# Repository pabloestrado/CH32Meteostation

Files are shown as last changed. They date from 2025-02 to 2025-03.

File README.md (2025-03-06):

# CH32 Meteostation

This project is a meteostation using the CH32V003A4M6 microcontroller. It includes functionalities for measuring temperature, humidity, and pressure, and displays the data on an SSD1306 OLED screen. The project also supports Bluetooth communication for remote data access.

## Features

- Temperature and humidity measurement using AHT20 sensor
- Pressure measurement using BMP280 sensor
- Display data on SSD1306 OLED screen
- Bluetooth communication using JDY-23 module
- Battery voltage monitoring
- Deep sleep mode for power saving

## Hardware Requirements

- CH32 microcontroller
- AHT20 temperature and humidity sensor
- BMP280 pressure sensor
- SSD1306 OLED display
- JDY-23 Bluetooth module
- Battery and power management components

## Software Requirements

- PlatformIO
- CH32V003 SDK
- I2C, UART, and GPIO libraries

## Setup

1. Clone the repository:
    ```sh
    git clone https://github.com/yourusername/CH32Meteostation.git
    cd CH32Meteostation
    ```

2. Open the project in PlatformIO:
    ```sh
    platformio init --board ch32v003
    ```

3. Build and upload the firmware:
    ```sh
    platformio run --target upload
    ```

## Usage

1. Power on the device.
2. The device will initialize and start measuring the environmental data.
3. The data will be displayed on the OLED screen.
4. Use a Bluetooth-enabled device to connect and retrieve data remotely.

## Code Overview

- `main.c`: The main application code, including initialization, measurement, display, and communication functions.
- `i2c.c` and `i2c.h`: I2C communication functions.
- `uart.c` and `uart.h`: UART communication functions.
- `ssd1306.c` and `ssd1306.h`: SSD1306 OLED display functions.
- `bmp280.c` and `bmp280.h`: BMP280 sensor functions.
- `aht20.c` and `aht20.h`: AHT20 sensor functions.

## License

This project is licensed under the MIT License. See the [LICENSE](LICENSE) file for details.

## Acknowledgements

- [PlatformIO](https://platformio.org/)
- [ch32fun](https://github.com/cnlohr/ch32fun)

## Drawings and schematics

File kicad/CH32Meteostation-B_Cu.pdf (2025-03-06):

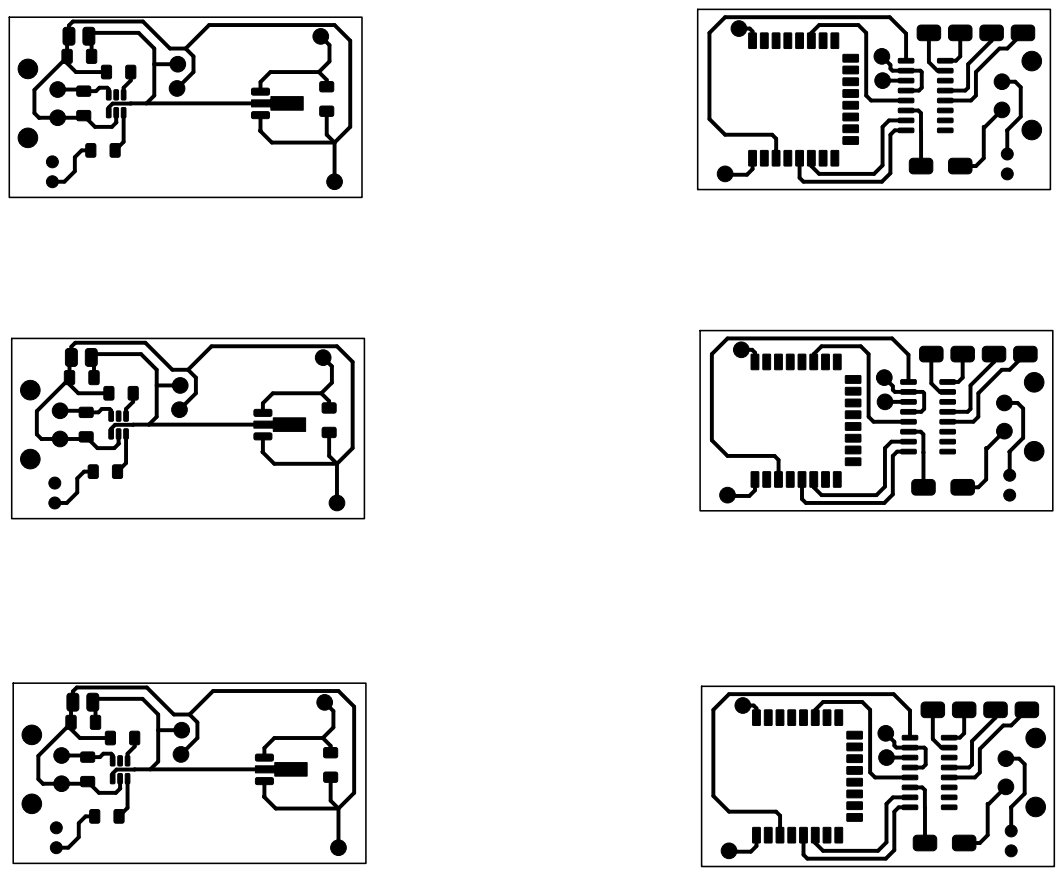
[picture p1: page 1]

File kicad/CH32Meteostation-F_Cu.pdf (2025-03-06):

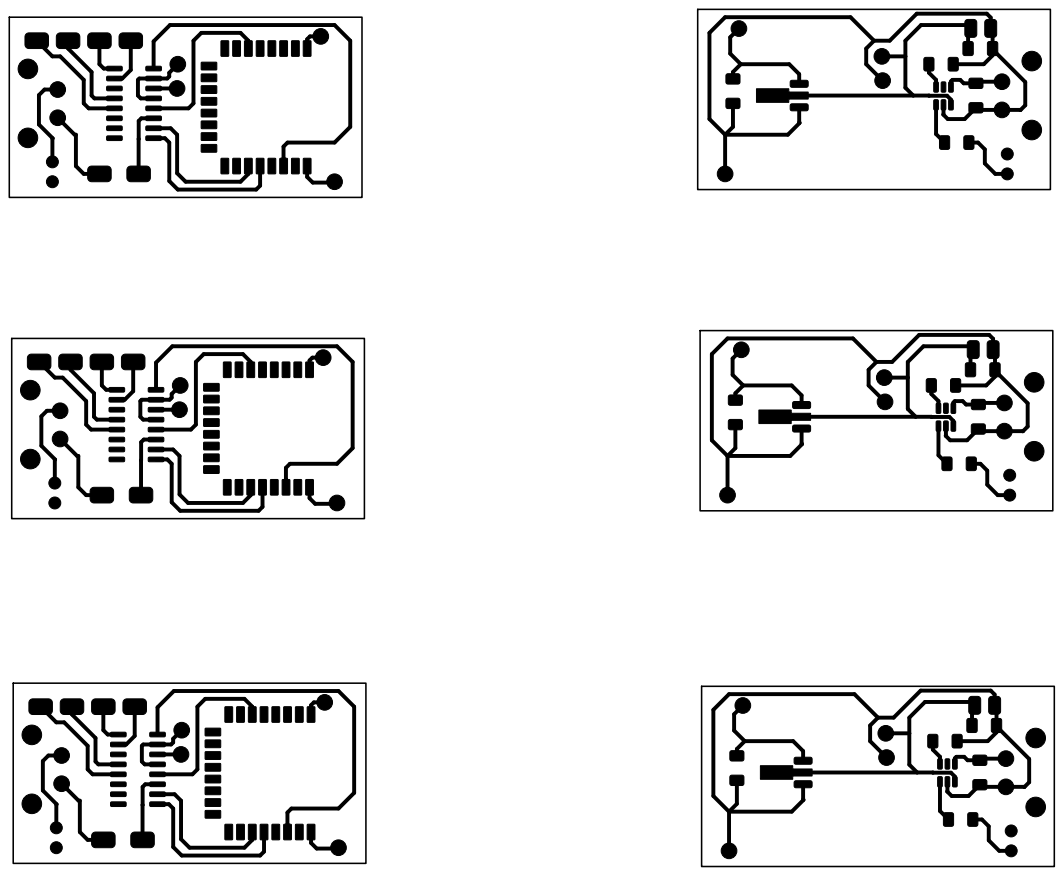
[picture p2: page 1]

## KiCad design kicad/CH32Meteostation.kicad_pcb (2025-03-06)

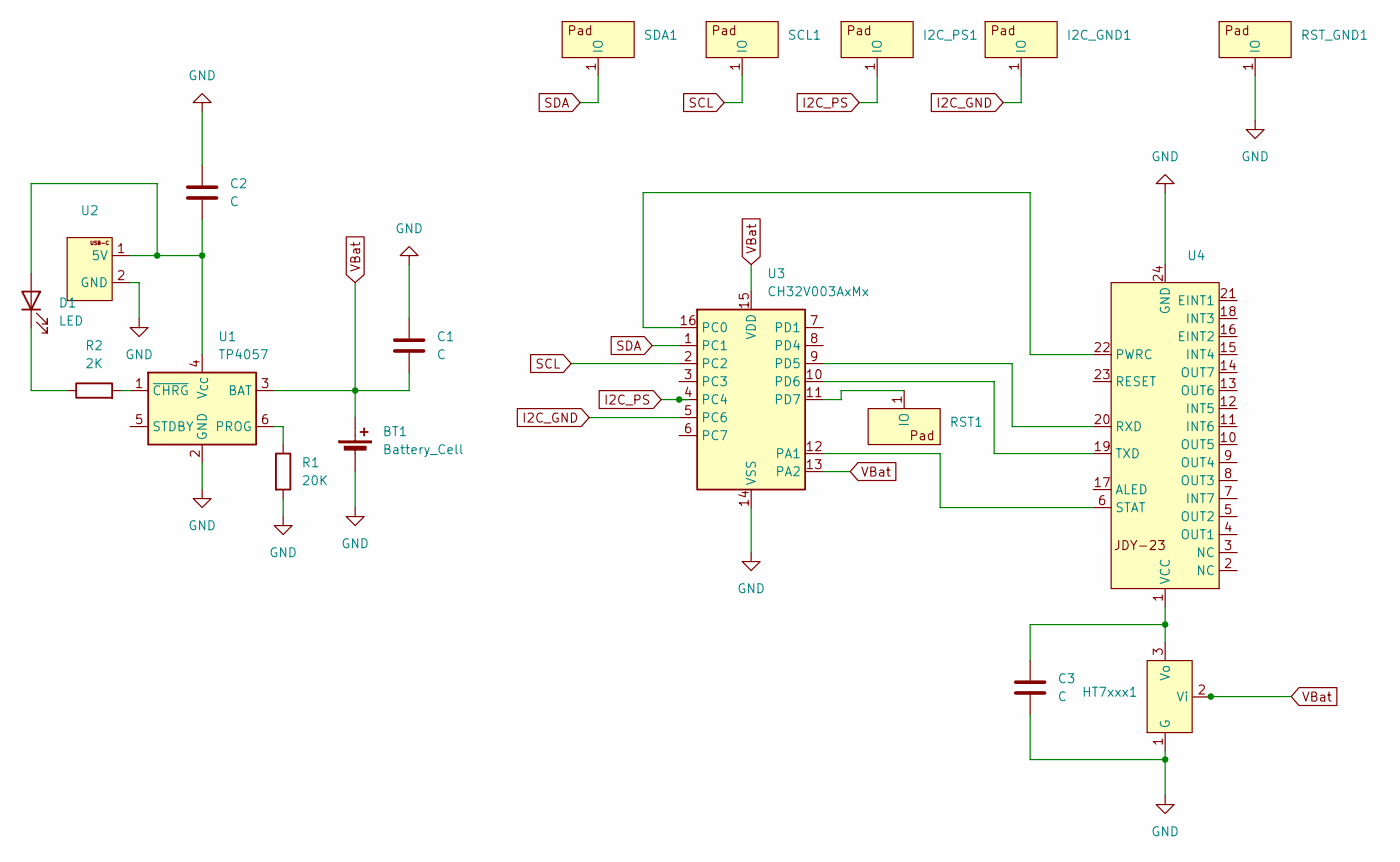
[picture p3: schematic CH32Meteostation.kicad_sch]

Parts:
BT1: Battery_Cell; 2-pin soldering pad
C1, C2, C3: C; C_1206_3216Metric_Pad1.33x1.80mm_HandSolder
D1: LED; DIP2 device
HT7xxx1: SOT-89-3_Handsoldering
I2C_GND1, I2C_PS1: Soldering pad
R1: 20K; R_1206_3216Metric_Pad1.30x1.75mm_HandSolder
R2: 2K; R_1206_3216Metric_Pad1.30x1.75mm_HandSolder
RST1: Soldering pad
RST_GND1: Soldering pad
SCL1: Soldering pad
SDA1: Soldering pad
U1: TP4057; TSOT-23-6
U2: USB_C_2pin-poweronly
U3: CH32V003AxMx; SOP-16_3.9x9.9mm_P1.27mm
U4: JDY-23

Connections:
GND: BT1.2 (-), C1.1, C2.1, C3.2, HT7xxx1.1 (G), R1.2, RST_GND1.1 (IO), U1.2 (GND), U2.2 (GND), U3.14 (VSS), U4.24 (GND)
I2C_GND: I2C_GND1.1 (IO), U3.5 (PC6)
I2C_PS: I2C_PS1.1 (IO), U3.4 (PC4)
unnamed: C2.2, D1.2 (A), U1.4 (V_{CC}), U2.1 (5V)
unnamed: D1.1 (K), R2.1
unnamed: C3.1, HT7xxx1.3 (Vo), U4.1 (VCC)
unnamed: RST1.1 (IO), U3.11 (PD7)
unnamed: R1.1, U1.6 (PROG)
unnamed: R2.2, U1.1 (~CHRG)
unnamed: U3.12 (PA1), U4.6 (STAT)
unnamed: U3.16 (PC0), U4.22 (PWRC)
unnamed: U3.9 (PD5), U4.20 (RXD)
unnamed: U3.10 (PD6), U4.19 (TXD)
SCL: SCL1.1 (IO), U3.2 (PC2)
SDA: SDA1.1 (IO), U3.1 (PC1)
VBat: BT1.1 (+), C1.2, HT7xxx1.2 (Vi), U1.3 (BAT), U3.13 (PA2), U3.15 (VDD)

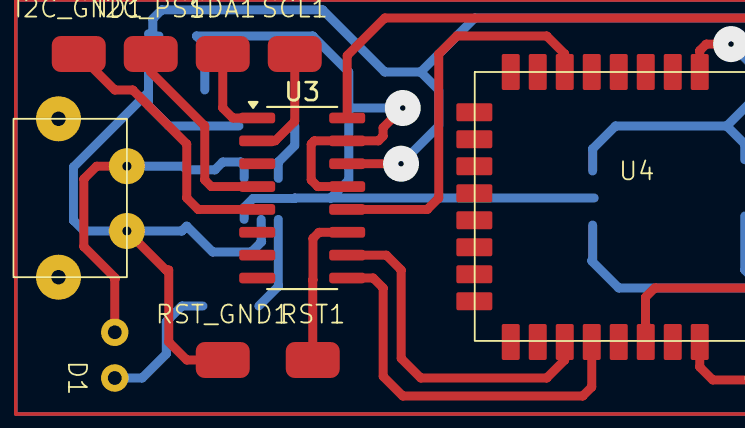
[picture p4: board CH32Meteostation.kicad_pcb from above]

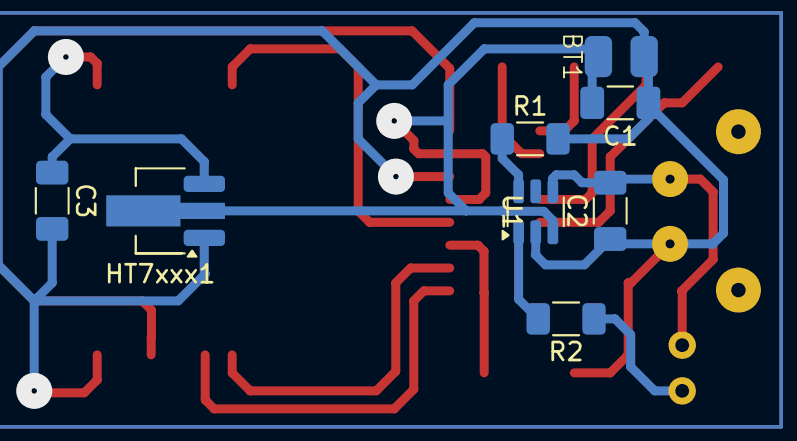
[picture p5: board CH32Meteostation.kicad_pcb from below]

Board: 2 copper layers, 18 parts (8 on the bottom side), 16 nets.

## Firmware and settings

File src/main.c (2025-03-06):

#define SSD1306_128X32


#include "ch32v003fun.h"
#include <stdio.h>
#include "ssd1306_i2c.h"
#include "ssd1306.h"

#include "i2c.h"
#include "bmp280.h"
#include "aht20.h"
#include "uart.h"

#define millis() (SysTick->CNT / DELAY_MS_TIME)


#define SCREEN_DELAY 10000 // Timeout before dimm screen
#define COMM_DELAY 10000	//Max time for UART communitation before sleep

#define WD_TIMEOUT_MS 15000 // Reset if stuck for more that 15s

#define I2C_GND_PIN PC6
#define I2C_VCC_PIN PC4
#define WAKEUP_PIN PA1
#define BAT_ADC_PIN ANALOG_0
#define JDY23_PWRC_PIN PC0

// Preshared key for BLE auth
#define AUTH_PSK "123"

uint8_t battery_level = 0;
uint8_t bmp280_errno = 0;
uint8_t aht20_errno = 0 ;

volatile uint8_t force_sleep = 0;
uint8_t authorized = 0;


BMP280Data bmp280_data;
AHT20Data aht20_data;


char buf[256] = {0};



void drawClock() {
	ssd1306_drawRect(0, 0,128, 32,0);
	ssd1306_fillRect(58, 0, 20, 3, 1);
	ssd1306_fillRect(58, 29, 20, 3, 1);
	ssd1306_drawLine(58, 3, 77, 29, 1);
	ssd1306_drawLine(77, 3, 58, 29, 1);
	ssd1306_refresh();
}

void drawAll() {
	ssd1306_setbuf(0);
	if (!aht20_errno) {
		sprintf(buf, "%d", abs((int16_t)aht20_data.temperature));
		
		if(aht20_data.temperature < 0) {
			ssd1306_fillRect(0, 15, 7, 3, 1);
		}
		ssd1306_drawstr_sz(8, 0, buf,1, fontsize_32x32);
		sprintf(buf, "%5d%%", (uint8_t)aht20_data.humidity);
		ssd1306_drawstr_sz(80, 24, buf,1, fontsize_8x8);
	}

	else{
		ssd1306_drawstr_sz(0, 0, "AHT20 failure!",1, fontsize_8x8);
	}

	if(!bmp280_errno) {
		sprintf(buf, "%6d mm", (uint32_t)((float)(bmp280_data.pressure) / 133.322f));
		ssd1306_drawstr_sz(80, 12, buf,1, fontsize_8x8);
	}
	else {
		ssd1306_drawstr_sz(80, 12, "ERROR",1, fontsize_8x8);
	}

	ssd1306_fillRect(100, 0, 24, 8, 1);
	ssd1306_fillRect(124, 2, 2, 4, 1);
	ssd1306_fillRect(101, 1, 22, 6, 0);
	ssd1306_fillRect(102, 2, battery_level / 5, 4, 1);

	ssd1306_refresh();
}



#define CMD_AUTH "AT+AUTH"
#define CMD_DATA "AT+DATA"
#define CMD_NAME "AT+NAME"
#define CMD_JDY23_READY "+Ready" //JDY-23 is booted

// Function to convert battery voltage in millivolts (vbat_mv) to battery percentage
int vbat_to_percentage(int vbat_mv) {
    // Clamping the values to ensure they're within the valid range
    if (vbat_mv <= 3000) {
        return 0;  // 0% when voltage is below 3000mV
    }
    if (vbat_mv >= 4100) {
        return 100;  // 100% when voltage is above 4100mV
    }

    // Linear mapping between 3000mV (0%) and 4100mV (100%)
    return (vbat_mv - 3000) * 100 / (4100 - 3000);
}

uint8_t measure() {
	// Sensors requires 80ms+ to start
	Delay_Ms(100);
	uint8_t bmp280_errno = BMP280_read(&bmp280_data);
	Delay_Ms(5); // We need it, for some reason BMP not working without small delay
	uint8_t aht20_errno = AHT20_read(&aht20_data);
	volatile uint16_t vref = funAnalogRead(ANALOG_8);
    volatile uint16_t vbat = funAnalogRead(BAT_ADC_PIN);
    volatile uint16_t vbat_mv = (1200 *vbat) / vref; // Battery voltage in milivolts
	printf("vbat %d mv %d vref %d\r\n", vbat, vbat_mv, vref);
	
	battery_level = vbat_to_percentage(vbat_mv);

	return bmp280_errno | aht20_errno;
}

uint8_t process_command(char *command) {

	if(strcmp(command, CMD_JDY23_READY) == 0) {
		// init JDY-23
		printf("JDY23 ready cmd\\r\n");
	}


	if(strcmp(command, "+OK") == 0) {
		// stub to ignore +OK from bt module cache
		command_ack();
		return 0;
	}

	if((strncmp(command, CMD_AUTH, strlen(CMD_AUTH)) == 0) &&
		strcmp((char*)(command + strlen(CMD_AUTH)), AUTH_PSK) == 0) {
		
		uart_print("+Authorized\r\n");
		authorized = 1;
		command_ack();
		return 0;
	}

	if (authorized && (strcmp(CMD_DATA, command) == 0)) {

		force_sleep = 1;
		if(measure() == BMP280_OK) {
			sprintf(buf, "{\"t\":\"%d\",\"h\":\"%d\",\"p\":\"%d\",\"b\":\"%d\"}", 
				(uint16_t)aht20_data.temperature, 
				(uint16_t)aht20_data.humidity, 
				(uint32_t)((float)(bmp280_data.pressure) / 133.322f),
				battery_level+1);
			
			uart_print(buf);
			uart_print("\r\n");
			printf("%s\r\n", buf);
			command_ack();
			return 0;
		}
		else
		{
			uart_print("{\"err\":\"sensor failure\"}\r\n");
			command_ack();
			return 0;
		}
	}


	if (authorized && (strncmp(command, CMD_NAME, strlen(CMD_NAME)) == 0)) {
		printf("Configure BLE\n");
		funDigitalWrite(JDY23_PWRC_PIN, 0);
		Delay_Ms(200);
		uart_print("AT+MAC");
		uart_print("\r\n");
		Delay_Ms(200);
		uart_print(command);
		uart_print("\r\n");
		Delay_Ms(200);
		uart_print(command);
		uart_print("\r\n");
		Delay_Ms(200);
		uart_print("AT+STARTEN0");
		uart_print("\r\n");
		Delay_Ms(200);
		uart_print("AT+STARTEN0");
		uart_print("\r\n");
		Delay_Ms(200);
		uart_print("AT+STARTEN");
		uart_print("\r\n");
		Delay_Ms(200);
		uart_print("AT+SLEEP2");
		uart_print("\r\n");
		Delay_Ms(200);
		uart_print("AT+SLEEP");
		uart_print("\r\n");
		Delay_Ms(200);
		uart_print("AT+ADVIN8");
		uart_print("\r\n");
		Delay_Ms(200);
		uart_print("AT+RST");
		uart_print("\r\n");
		Delay_Ms(200);
		funDigitalWrite(JDY23_PWRC_PIN, 1);
		command_ack();
		return 0;
	}

	uart_print("+Unknown ");
	uart_print(command);
	uart_print("\r\n");	
	command_ack();
	return 1;
}

void EXTI7_0_IRQHandler( void ) __attribute__((interrupt));
void EXTI7_0_IRQHandler( void ) 
{
	SystemInit();
    if ((EXTI->INTFR & EXTI_Line1)) {
        EXTI->INTFR |= EXTI_Line1;
		//printf("Exti line 1\n");
    }
	else {
		//printf("Exti other\n");
	}
}

void btinit() {

}

void disconnect() {
	funDigitalWrite(JDY23_PWRC_PIN, 0);
	Delay_Ms(20);
	uart_print("AT+DISC\r\n");
	// Delay_Ms(200);
	// uart_print("AT+ALED0\r\n");
	Delay_Ms(20);
	funDigitalWrite(JDY23_PWRC_PIN, 1);
}

void TIM2_IRQHandler( void ) __attribute__((interrupt));
void TIM2_IRQHandler( void ) {
	if ((TIM2->INTFR & TIM_CC1IF) && (TIM2->CNT == WD_TIMEOUT_MS)) {		
		//printf("Tim2 interrupt 0x%x cnt 0x%d\n", TIM2->INTFR, TIM2->CNT);
		printf("Software WDG reset intfr 0x%x cnt %d\n", TIM2->INTFR, TIM2->CNT);
		PFIC->SCTLR |= 1 << 31; //SYSRESET
	}
	TIM2->INTFR =0x00;
}

void init() {
	

	SystemInit();

	// Run with 6 Mhz system core clock
	RCC->CFGR0 |= RCC_HPRE_DIV4;

	// while (!(RCC->CTLR & RCC_HSIRDY)) {
	// 	// Wait until the prescaler is applied
	// }


	// GPIO config
	funGpioInitAll();

	//GPIOA: Set to output
	GPIOA->CFGLR = (GPIO_CNF_IN_PUPD<<(4*2)) |
				   (GPIO_CNF_IN_PUPD<<(4*1));
	// GPIOC: Set to input with mixed pull-up / pull-down
	GPIOC->CFGLR = (GPIO_CNF_IN_PUPD<<(4*7)) |
				   (GPIO_CNF_IN_PUPD<<(4*6)) |
				   (GPIO_CNF_IN_PUPD<<(4*5)) |
				   (GPIO_CNF_IN_PUPD<<(4*4)) |
				   (GPIO_CNF_IN_PUPD<<(4*3)) |
				   (GPIO_CNF_IN_PUPD<<(4*2)) |
				   (GPIO_CNF_IN_PUPD<<(4*1)) |
				   (GPIO_CNF_IN_PUPD<<(4*0));
	// GPIOD: D2 set to input pull-up
	GPIOD->CFGLR = (GPIO_CNF_IN_PUPD<<(4*7)) |
				   (GPIO_CNF_IN_PUPD<<(4*6)) |
				   (GPIO_CNF_IN_PUPD<<(4*5)) |
				   (GPIO_CNF_IN_PUPD<<(4*4)) |
				   (GPIO_CNF_IN_PUPD<<(4*3)) |
				   (GPIO_CNF_IN_PUPD<<(4*2)) |
				   (GPIO_CNF_IN_FLOATING<<(4*1)) |
				   (GPIO_CNF_IN_PUPD<<(4*0));


	funPinMode(I2C_GND_PIN, GPIO_Speed_2MHz | GPIO_CNF_OUT_OD);
	funPinMode(I2C_VCC_PIN, GPIO_Speed_2MHz | GPIO_CNF_OUT_PP);
	funPinMode(WAKEUP_PIN, GPIO_CFGLR_IN_PUPD);
	funPinMode(JDY23_PWRC_PIN, GPIO_Speed_2MHz | GPIO_CNF_OUT_OD);
	// Supply i2c power
	funDigitalWrite(I2C_VCC_PIN, 1);

	funDigitalWrite(JDY23_PWRC_PIN,1);

	// ADC config
	funAnalogInit();
	funPinMode(PA2, GPIO_CNF_IN_ANALOG);

	// PA1 interupt wakeup
	AFIO->EXTICR |= AFIO_EXTICR_EXTI1_PA;
	EXTI->INTENR |= EXTI_INTENR_MR1; // Enable EXT1
	EXTI->RTENR |= EXTI_RTENR_TR1;
	RCC->APB2PCENR |= RCC_AFIOEN;
    NVIC_EnableIRQ( EXTI7_0_IRQn );
	
	//printf("File: %s, Line: %d\n", __FILE__, __LINE__);

	// Deep Sleep config
	PWR->CTLR |= PWR_CTLR_PDDS;
	PFIC->SCTLR |= 1 << 2;

	// Init TIM2 to use it as watchdog (IWDG cat be used because it resetc MCU in  deep sleep mode)
	RCC->APB1PCENR |= RCC_APB1Periph_TIM2;

    // Reset TIM2 to init all regs
	RCC->APB1PRSTR |= RCC_APB1Periph_TIM2;
	RCC->APB1PRSTR &= ~RCC_APB1Periph_TIM2;
	
	// set TIM2 clock prescaler divider 
	TIM2->PSC = 5999; // on 6MHZ HSI tick each milisecond
	// set PWM total cycle width
	TIM2->ATRLR = WD_TIMEOUT_MS;
	
	// enable auto-reload of preload
	TIM2->CTLR1 |= TIM_ARPE;

    // Direction increment, enable
	TIM2->CTLR1 &= !TIM_DIR;
	TIM2->CTLR1 |= TIM_CEN;

	// Enable CH1 interupt
	TIM2->DMAINTENR = TIM_CC1IE;

	TIM2->CH1CVR = WD_TIMEOUT_MS;
	TIM2->CNT = 900;

	TIM2->INTFR = 0;
	NVIC_EnableIRQ( TIM2_IRQn );

	//printf("File: %s, Line: %d\n", __FILE__, __LINE__);

	uart_init();

	//printf("File: %s, Line: %d\n", __FILE__, __LINE__);
	
    if(i2c_init() != I2C_OK) {
		printf("Failed to init the I2C Bus\n");
		uart_print("+I2CFAILURE\r\n");
	}
	// Reset SysTick
	SysTick->CNT = 0;

	authorized = 0;

	force_sleep = 0;

	uart_print("+MCUREADY\r\n");

	// Sink power for screen and sensor GND
	funDigitalWrite(I2C_GND_PIN, 0);

	Delay_Ms(50);

	//printf("File: %s, Line: %d\n", __FILE__, __LINE__);

	//ssd1306 deinit
	i2c_begin_transmisison(SSD1306_I2C_ADDR, I2C_MODE_WRITE);
	uint8_t ssd1306_deinit_cmd[] = {
		SSD1306_DISPLAYOFF
	};
	i2c_transmit_data(ssd1306_deinit_cmd, sizeof(ssd1306_deinit_cmd));
	i2c_end_transmisison();
	ssd1306_init();

	//printf("File: %s, Line: %d\n", __FILE__, __LINE__);
}

void deinit() {

	// // deinit display

	// printf("deinit start\n");
	// ssd1306_setbuf(0);
	// printf("deinit refrest\n");
	// ssd1306_refresh();
	// printf("deinit middle\n");
	// i2c_begin_transmisison(SSD1306_I2C_ADDR, I2C_MODE_WRITE);
	// uint8_t ssd1306_deinit_cmd[] = {
	// 	SSD1306_DISPLAYOFF
	// };
	// i2c_transmit_data(ssd1306_deinit_cmd, sizeof(ssd1306_deinit_cmd));
	// i2c_end_transmisison();



	i2c_deinit();
	uart_deinit();

    //Disable and reset ADC
	funPinMode(PA2, GPIO_CNF_OUT_PP);
    RCC->APB2PCENR &= ~RCC_APB2Periph_ADC1;
    RCC->APB2PRSTR |= RCC_APB2Periph_ADC1;

	funDigitalWrite(I2C_VCC_PIN, 0);
	funPinMode(I2C_VCC_PIN, GPIO_CNF_OUT_OD);
	funPinMode(I2C_GND_PIN, GPIO_CNF_OUT_OD);

	//power off SCL
	// funPinMode(PC1, GPIO_CNF_OUT_OD);
	// funPinMode(PC1, GPIO_CNF_OUT_OD);
	funPinMode(PD1, GPIO_CNF_IN_PUPD); // disable floating in SWIO pin for power eficiency
	
	//funPinMode(JDY23_PWRC_PIN, GPIO_CNF_IN_PUPD);

	//deinit timer
	RCC->APB1PCENR &= !RCC_APB1Periph_TIM2;

    // Reset TIM2 to init all regs
	RCC->APB1PRSTR |= RCC_APB1Periph_TIM2;
	RCC->APB1PRSTR &= ~RCC_APB1Periph_TIM2;

	TIM2->CNT = 0;
	TIM2->INTFR = 0;
	NVIC_DisableIRQ( TIM2_IRQn );
}


void drawBluetoothLogo() {
  	// Draw the vertical central line
	ssd1306_drawLine(64, 6, 64, 26, 1);
	ssd1306_drawLine(64, 26, 71, 19, 1);
	ssd1306_drawLine(64, 6, 71, 11, 1);
	ssd1306_drawLine(62, 14, 71, 19, 1);
	ssd1306_drawLine(62, 18, 71, 11, 1);
}


void deepsleep() {
	printf("Sleep\n");
	uart_print("+SLEEP\r\n");
	Delay_Ms(50);
	disconnect();
	deinit();
	Delay_Ms(1); // Give a chance to deliver last DATA byte
	__WFI();
	
	//printf("Init start\n");
	init();
	//printf("Init done\n");
	uart_print("+WAKEUP\r\n");
	printf("Wake up\n");
	Delay_Ms(50);
	drawBluetoothLogo();
	ssd1306_refresh();

	//printf("ONWAKEUPSTAT: 0x%x \n", USART1->STATR);
}


int main()
{
	// 48MHz internal clock

	init();

	drawClock();

	measure();
	drawAll();
	
	while(millis() <= SCREEN_DELAY) {
		if(is_command_received()) {
			// printf("Cmd: %s\n", get_command());

			// int i = 0;
			// while(command[i] != 0) {
			// 	printf("0x%x %c\n", command[i], command[i]);
			// 	i++;
			// }

			process_command(get_command());
		}


		Delay_Ms(500);
		printf("T2CNT: %d \n", TIM2->CNT);
	}

	ssd1306_setbuf(0);
	ssd1306_refresh();
	
	funDigitalWrite(I2C_GND_PIN, 1);

	deepsleep();

	printf("AFTERDSSTAT: 0x%x \n", USART1->STATR);

	while(1) {
		if(is_command_received()) {
			// printf("Command: %s\n", get_command());

			// int i = 0;
			// while(command[i] != 0) {
			// 	printf("0x%x %c\n", command[i], command[i]);
			// 	i++;
			// }

			process_command(get_command());
		}
		if((millis() > COMM_DELAY) || (force_sleep == 1) ) {
			
			deepsleep();
			
			
		}
		//iwdg_feed();

		Delay_Ms(500);
		printf("STAT: 0x%x \n", USART1->STATR);
	}
}

/*
AT+AUTH123
AT+DATA
 */

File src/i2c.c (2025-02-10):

/*
 * MIT License
 * 
 * Copyright (c) 2025 Pavlo Romaniuk
 * 
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
 * THE SOFTWARE IS PROVIDED "AS IS", WITHOUT WARRANTY OF ANY KIND, EXPRESS OR
 * IMPLIED, INCLUDING BUT NOT LIMITED TO THE WARRANTIES OF MERCHANTABILITY,
 * FITNESS FOR A PARTICULAR PURPOSE AND NONINFRINGEMENT. IN NO EVENT SHALL THE
 * AUTHORS OR COPYRIGHT HOLDERS BE LIABLE FOR ANY CLAIM, DAMAGES OR OTHER
 * LIABILITY, WHETHER IN AN ACTION OF CONTRACT, TORT OR OTHERWISE, ARISING FROM,
 * OUT OF OR IN CONNECTION WITH THE SOFTWARE OR THE USE OR OTHER DEALINGS IN THE
 * SOFTWARE.
 */


#include "ch32v003fun.h"
#include "i2c.h"


/**
 * @brief  Begins an I2C transmission, either for reading or writing to a specific address.
 * 
 * This function initializes the I2C transmission by starting the master mode and setting up 
 * the address and transmission direction (read or write). It handles timeouts during each step
 * to ensure the operation is completed successfully.
 *
 * @param addr     The I2C address of the slave device (7-bit address).
 * @param transmit Specifies the direction of the transmission:
 *                 - `I2C_MODE_READ`: Read operation.
 *                 - `I2C_MODE_WRITE`: Write operation.
 * 
 * @return uint8_t 
 *   - `I2C_OK` (0): Transmission started successfully.
 *   - `I2C_ERR_BUSY` (1): Timeout waiting for the bus to become available.
 *   - `I2C_ERR_MASTER` (2): Timeout while asserting master mode.
 *   - `I2C_ERR_TIMEOUT` (4): Timeout during the data transmission initialization.
 * 
 * @note   The function handles setting up the master mode, clearing any previous errors, 
 *         and checking flags at each step to ensure proper operation.
 */
uint8_t i2c_begin_transmisison(uint8_t addr, uint8_t mode) {
    // Wait for the I2C bus to be free, with timeout to prevent hanging
    int32_t timeout = I2C_TIMEOUT;
    while (I2C1->STAR2 & I2C_STAR2_BUSY) { 
        if (--timeout < 0) {
            #ifdef I2C_DEBUG
            printf("I2C Timeout waiting bus\n");
            #endif
            return I2C_ERR_BUSY;
        }
    }

    // Clear Acknowledge failure (AF) bit if set from previous operation
    I2C1->STAR1 &= ~I2C_STAR1_AF;

    // Generate a START condition on the I2C bus
    I2C1->CTLR1 |= I2C_CTLR1_START;
    timeout = I2C_TIMEOUT;

    // Wait for the start condition to be acknowledged by checking flags
    while ((I2C1->STAR1 != 0x0001) || (I2C1->STAR2 != 0x0003)) { // BUSY, MSL, SB flags
        if (--timeout < 0) {
            #ifdef I2C_DEBUG
            printf("I2C start timeout\n");
            #endif
            return I2C_ERR_MASTER;
        }
    }

    // Send the 7-bit address with write bit (0) or read bit (1)
    I2C1->DATAR = (addr << 1) & 0xFE;  // Address | Write

    // Wait for transmission to be initialized, checking flags again
    timeout = I2C_TIMEOUT;
    while ((I2C1->STAR1 != 0x0082) || (I2C1->STAR2 != 0x0007)) { // BUSY, MSL, SB flags
        if (--timeout < 0) {
            #ifdef I2C_DEBUG
            printf("I2C transmit init timeout\n");
            #endif
            return I2C_ERR_TIMEOUT;
        }
    }

    // If a read operation is requested, set the read flag and configure accordingly
    if (mode == I2C_MODE_READ) {
        I2C1->CTLR1 |= I2C_CTLR1_ACK;  // Enable ACK for receiving

        // Generate start condition in receiver mode
        I2C1->CTLR1 |= I2C_CTLR1_START;
        timeout = I2C_TIMEOUT;

        // Wait for the master mode and slave address match, indicating readiness to receive
        while ((I2C1->STAR1 != 0x0001) || (I2C1->STAR2 != 0x0003)) { // BUSY, MSL, SB flags
            if (--timeout < 0) {
                #ifdef I2C_DEBUG
                printf("I2C start in receiver mode timeout\n");
                #endif
                return I2C_ERR_TIMEOUT;
            }
        }

        // Send the 7-bit address with read bit set (1)
        I2C1->DATAR = (addr << 1) | 0x01;  // Address | Read

        // Wait for acknowledgment of the address, master mode with receive ready flags
        timeout = I2C_TIMEOUT;
        while ((I2C1->STAR1 != 0x0002) || (I2C1->STAR2 != 0x0003)) { // BUSY, MSL, SB flags
            if (--timeout < 0) {
                #ifdef I2C_DEBUG
                printf("Receive init timeout\n");
                #endif
                return I2C_ERR_TIMEOUT;
            }
        }
    }

    return I2C_OK;  // Success
}

/**
 * @brief  Ends the current I2C transmission by generating a STOP condition.
 * 
 * This function generates a STOP condition on the I2C bus to indicate the end of a transmission.
 * It also clears any pending errors (e.g., acknowledge failure or arbitration loss) to prepare 
 * for the next transmission.
 */
void i2c_end_transmisison() {
    // Generate a STOP condition on the I2C bus
    I2C1->CTLR1 |= I2C_CTLR1_STOP;

    // Clear Acknowledge failure (AF) and Arbitration Loss (ARLO) bits to avoid issues in future operations
    I2C1->STAR1 &= ~I2C_STAR1_AF;
    I2C1->STAR1 &= ~I2C_STAR1_ARLO;
}


/**
 * @brief  Transmits a sequence of data bytes to the I2C bus.
 * 
 * This function writes multiple bytes of data to the I2C bus. Each byte is sent sequentially, 
 * and the function waits for the data register to be empty before sending the next byte. 
 * It supports error checking with a timeout for each byte transmission.
 * 
 * @param data     Pointer to the data buffer to transmit.
 * @param length   The number of bytes to transmit.
 * 
 * @return uint8_t 
 *   - `I2C_OK` (0): All data sent successfully.
 *   - `I2C_ERR_TIMEOUT` (4): Timeout while waiting for data to be transmitted.
 * 
 * @note   Debugging messages will be printed for each byte sent if `I2C_DEBUG` is defined.
 */
uint8_t i2c_transmit_data(uint8_t *data, uint16_t length) {
    int16_t timeout = I2C_TIMEOUT;

    // Transmit each byte in the data buffer
    for (uint16_t cnt = 0; cnt < length; cnt++) {
        I2C1->DATAR = *data;  // Write the byte to the data register

        // Wait for the data to be transmitted (TXE flag)
        while (!(I2C1->STAR1 & I2C_STAR1_TXE)) {
            if (--timeout < 0) {
                #ifdef I2C_DEBUG
                printf("Send timeout\n");
                #endif
                return I2C_ERR_TIMEOUT;
            }
        }

        #ifdef I2C_DEBUG
        printf("Byte sent: 0x%02X\n", *data);  // Debug message
        #endif

        data++;  // Move to the next byte in the buffer
    }

    return I2C_OK;  // Success
}
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

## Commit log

2025-02-02 sensors working
2025-03-06 Add KiCad files
    [CH32Meteostation.kicad_pcb, CH32Meteostation.kicad_sch]
